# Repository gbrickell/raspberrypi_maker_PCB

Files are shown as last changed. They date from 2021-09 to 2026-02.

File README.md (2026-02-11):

# Raspberry Pi PCB v5.0

The aim of this project was to consolidate a number of components previously used in separate breadboard-based educational projects, along with some additional options, in a more robust, permanent assembly using a custom Printed Circuit Board (PCB). 
This new platform would then allow an even wider range of projects to be developed, but it should be noted that all the various uses profiled here can still be carried out without the use of the custom PCB which just makes the various connections to the Raspberry Pi a lot easier.

Full details about the project are published at <a href="https://onlinedevices.org.uk/Raspberry+Pi+Maker+PCB" target="_blank" >this link</a> and the designs for a small number of associated custom 3D printed components can be downloaded from <a href="https://www.prusaprinters.org/prints/68834-raspberry-pi-maker-PCB-stands" target="_blank">here</a>.

The various sections below provide more detail on:
 - the documentation made available in the 'documentation' folder;
 - the design details for the PCB made available in the 'PCB_design_files' folder; and
 - the software available as downloads from the 'Raspberry_Pi_SBC_code' folder.

## Documentation

A robust permanent module, that connects to the Raspberry Pi GPIO pins, can be created by soldering a set of components into the custom Printed Circuit Board (PCB v5.0). The module design, as shown below, includes a number of on-board devices that can be controlled by the Pi (e.g. buzzer, LEDs, etc.), but also allows a wide range of further components to be connected to the PCB enabling more Pi controlled systems to be built and explored.

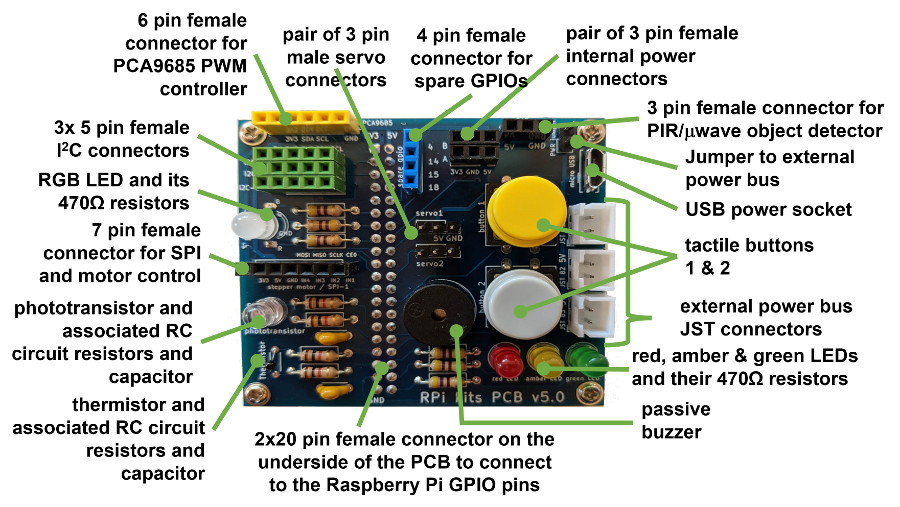
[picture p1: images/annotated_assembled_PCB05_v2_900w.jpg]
&nbsp; &nbsp; 

Documentation is made available for usage exploration of:
 - basic electronic functions
 - LCD, OLED and LED displays
 - servo, stepper and drive motor control
 - various sensors
 - 433Mz ASK/OOK RF communications, and 
 - image taking with a USB camera

## Custom PCB design

The custom PCB (now at v5.0) was designed using KiCAD and the layout has been defined to allow headers and other connectors for all the components needed to build a fully populated module.

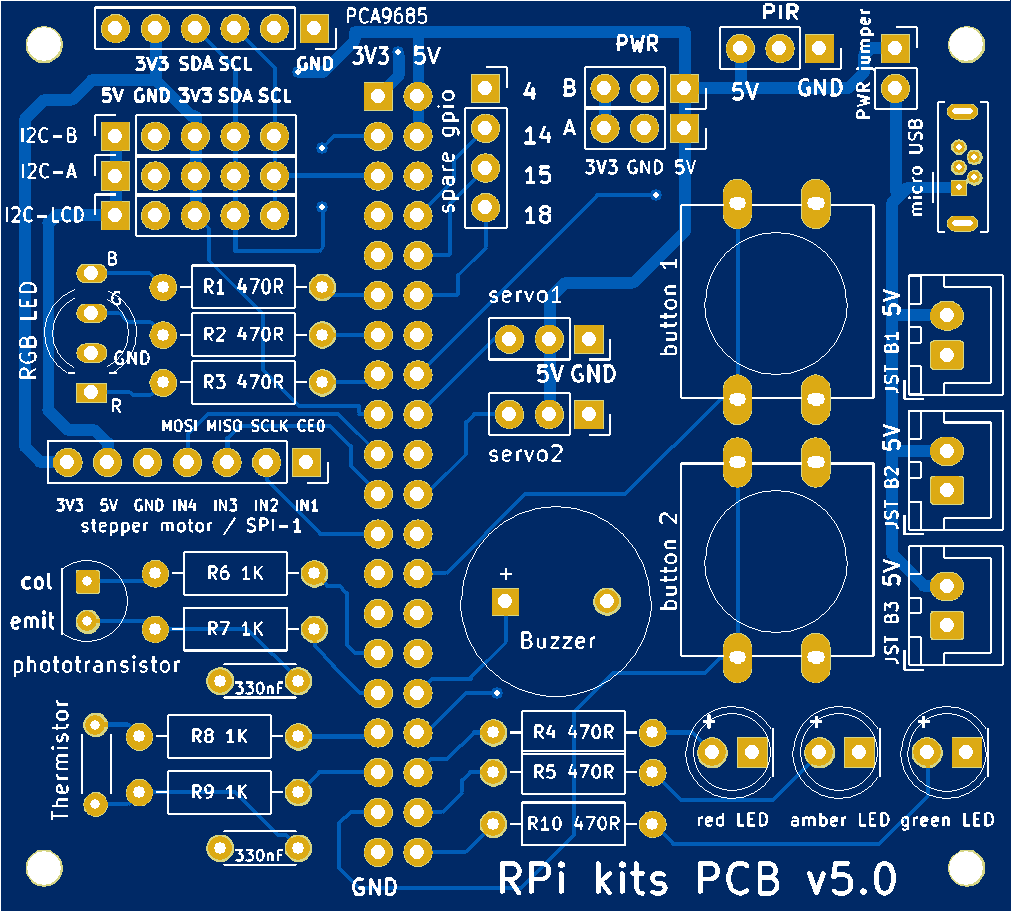
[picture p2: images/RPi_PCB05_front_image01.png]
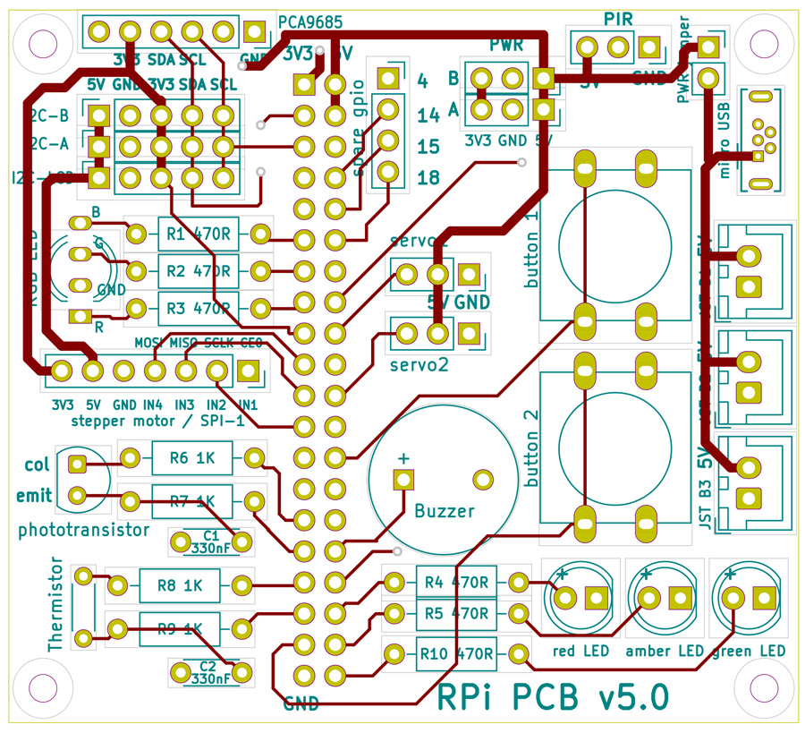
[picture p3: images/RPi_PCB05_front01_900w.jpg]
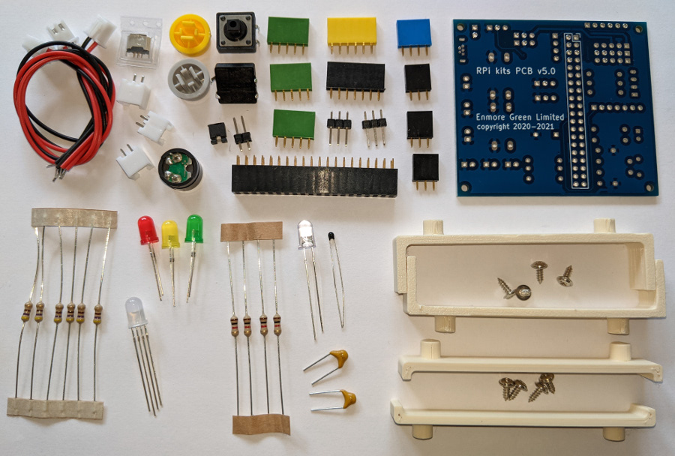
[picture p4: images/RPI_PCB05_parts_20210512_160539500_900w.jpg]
 &nbsp; &nbsp;  &nbsp; &nbsp;   

Gerber files for the PCB design can be downloaded from the PCB_design_files folder.

## Raspberry Pi SBC code
The code and documentation has been updated to allow for a generalised username instead of the 'old' default username 'pi', and for the use of Python using the Bookworm OS with the use of a Virtual Environment also described.

An installation script is also provided that not only downloads all the code and documentation but also installs all the various libraries/modules needed by the code.

Example code is provided, just for the 'basic electronics' exploration, using the Pi's Scratch offline versions 1.4, 2 and 3, so that all the common Raspberry Pi SBC formats that can run Scratch in some form has an option.

Python example code is provided for all the 'exploration' areas and can usually be run using the Thonny IDE on a Pi SBC, but suggested CLI commands for the user are also provided in the code as a comment, where the installed folders are assumed to be: /home/YOURUSERNAME/RPi_maker_PCB5/foldername/ where 'foldername' is for one of the specific areas that is being explored, e.g. displays, sensors, etc.

The image taking code also assumes various folders for the storage of different types of 'taken' images and these folders are not always auto-created so the code should be checked so that the appropriate folders can be created before the code is run.

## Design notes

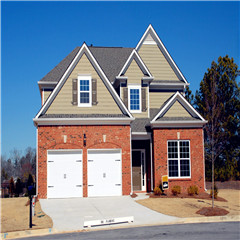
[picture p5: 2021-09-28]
Raspberry_Pi_SBC_code/displays/IPS_240X240_SPI/pic/pic-2.jpg

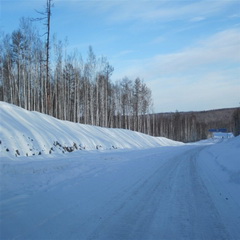
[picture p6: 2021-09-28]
Raspberry_Pi_SBC_code/displays/IPS_240X240_SPI/pic/pic-3.jpg

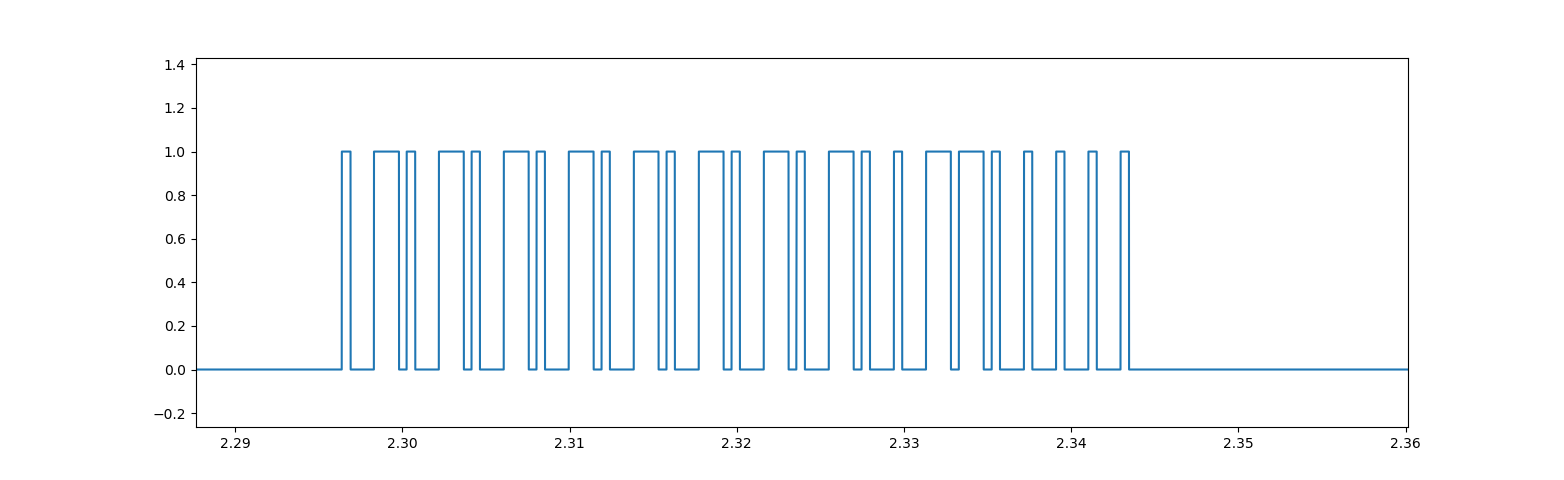
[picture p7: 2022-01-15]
images/button_B_signal.png

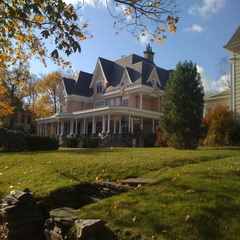
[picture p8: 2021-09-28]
Raspberry_Pi_SBC_code/displays/IPS_240X240_SPI/pic/pic-1.jpg

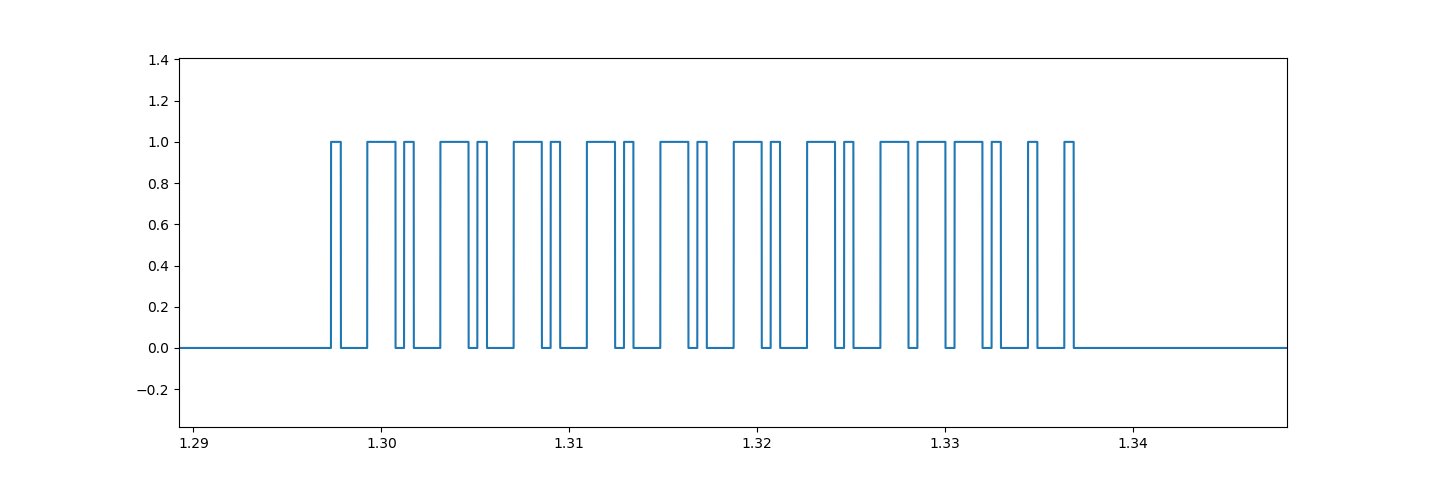
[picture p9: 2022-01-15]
images/button_A_signal.png

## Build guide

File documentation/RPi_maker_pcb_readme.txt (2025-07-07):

*********************************************************************************
RPi_maker_pcb_readme.txt - version control details for the Raspberry Pi Maker PCB
*********************************************************************************

required components version 2.0 September 2024
----------------------------------------------
  required components for use with the v5.0 PCB are listed in the RPi_PCB5_usage_documentation_v2-1.pdf
  and RPi_maker_pcb_getting_started_v2-0.pdf documents

  please note:
  ------------
  all electronic and electrical components need to be carefully recycled 
  but we would much prefer for you to pass this equipemnt on to another 
  user if you have no further use for it. 

*******************************************************************	
software & documentation version 2.0  September 2024
-------------------------------------------------------------------
  description: updated version with content to support usage with Raspberry Pi SBCs using the Bookworm OS 

  ** documentation ** 
    RPi_maker_pcb_readme.txt - this document which is updated whenever a new version is released
    RPi_maker_pcb_getting_started_v2-0.pdf - Raspberry Pi Maker PCB getting started leaflet v2.0 September 2024
    RPi_PCB5_usage_documentation_v2-1.pdf - Raspberry Pi Maker PCB detailed usage documentation v2.1 September 2024

  ** Scratch, Python and other software files **
  
  * Raspberry Pi single board computer (SBC) code:
  
  electronic basics
  -----------------
  Scratch 1.4 - LED_button_buzzer.sb
              - LED_button_flash.sb
			  - LED_flash.sb
			  - LED_red_green_flash.sb
			  - LED_RGB_flash.sb
  Scratch 2   - LED_button_buzzer.sb2
              - LED_button_flash.sb2
			  - LED_flash.sb2
			  - LED_red_green_flash.sb2 
			  - LED_RGB_flash.sb2
  Scratch 3   - LED_button_buzzer.sb3
              - LED_button_flash.sb3
			  - LED_flash.sb3
			  - LED_red_green_flash.sb3 
			  - LED_RGB_flash.sb3
  Python - LED_flash.py
	     - LED_red_green_flash.py
		 - LED_red_amber_green_flash.py
	     - LED_button_flash.py
	     - LED_button_buzzer.py
		 - buzzer_player.py
  web code      - LED1_flash_web.py
  web css       - normalize_advanced.css	
                - skeleton_advanced.css
  web images    - favicon.png
                - RPi_PCB05_20210419_160549156_900w.jpg
			    - RPi_PCB05_front_image01.png
  web templates - electronics_header_insert.html
                - electronics_layout.html
				- electronics_select_mode1.html
				- led1_setup_mode.html
				- run_led1.html

  image taking
  ------------
  Python - button_led_take_image.py
         - button_led_take_video.py
		 - button_take_image.py
	     - button_take_video.py
		 - button_timer_take_image.py
		 - button_timer_take_video.py
		 - PIR_take_image.py
		 - sort_number_symlink_files.py
		 - timelapse_cron_take_annotated_image.py
		 - timelapse_cron_take_image.py
  web code      - image_camera_usb_opencv_annotate.py
                - image_streaming_app_root_annotate.py
				- image_streaming_app_user_annotate.py
  web css       - normalize_advanced.css	
                - skeleton_advanced.css
  web images    - favicon.png
                - Starter_PCB01_20210518_132528401_900w.jpg
			    - Starter_PCB01_front_image.png
  web templates - cam_options_setup.html
                - cam_setup_mode.html
				- header_insert.html
				- layout.html
				- select_mode.html
				- stream_video_mode.html
  
  displays
  --------
  Python - code for IPS_240X240_SPI display
         - code for IPS_80x160_SPI display
		 - code for LCD_1602_i2c display
		 - code for MAX7219_7segment_LED display
		 - code for OLED_128x64_I2C display
		 - code for TM1637_7segment_LED display
    
  motor control
  -------------
  Python - code for drive motor control
         - code for servo motor control
		 - code for stepper motor control
  web code - web front end code for motor control
  
  RF_communication
  ----------------
  Python - code for C218D001C + FS1000A communications
         - code for RXB8 communications
		 - code for SRX882 + STX882 communications
  
  sensors
  -------
  Python - code for light sensor data capture
         - code for magnetic sensor data capture
		 - code for MPR121 touch sensor data capture
		 - code for object_detection sensor data capture
		 - code for pressure sensor data capture
		 - code for temperature sensor data capture
		 - code for TTP229 touch keypad data capture

copyright 2021-2024 Geoff Brickell

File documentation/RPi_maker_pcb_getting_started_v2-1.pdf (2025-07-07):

The aim of this evolving project is to provide access to an expanding library of example code to allow a digital maker to explore and control many different components and devices.
This is achieved by using a custom PCB with a set of defined components, listed above, to assemble a populated module that can connect to any of the family of Raspberry Pi single board computers (SBCs) with 2x20 GPIO pins. Example software is available to download to Raspberry Pi SBCs along with a “Raspberry Pi Maker PCB Usage Documentation” PDF providing assembly and detailed usage instructions, along with other support documents.
Whilst any model of 2x20 GPIO pin Raspberry Pi is OK, if a new Pi is being purchased the Raspberry Pi5 or Pi400 with at least 2GB of memory is recommended as well as a SD card that is at least 32GB. You should also be using the latest Bookworm version of the operating system. If you have an earlier operating system version, you should carry out an update or create/ install a new SD card before installing the Raspberry Pi software and documentation detailed overleaf, for the use of this Maker PCB.
© 2021-25 Geoff Brickell | version 2.1 | July 2025

## Required component summary:

1x printed circuit board (PCB) | 4x 1kΩ resistors
1x red LED | 2x 330nF capacitors
1x amber LED | 1x Thermistor 10kΩ NTC
1x green LED | 1x Phototransistor
1x RGB LED | 2x tactile buttons
6x 470Ω resistors | 1x passive buzzer
3x JST sockets + plugs with leads | 1x USB type B micro socket
1x 1row x 6P female yellow header | 3x 1row x 5P female green headers
1x 1row x 4P female blue header | 3x 1row x 3P female black headers
1x 1row x 7P female black header | 1x 2row x 20P female black header
2x 1row x 3P male black header | 1x + 1x 1row x 2P male black header + jumper
2x 3D printed PCB ‘stands’ + 4x 6mm M2 self-tap screws | 2x 3D printed Raspberry Pi ‘stands’ + 4x 6mm M2 self-tap screws

# Getting started with your Raspberry Pi Maker PCB

$ wget -O /home/YOURUSERNAME/RPi_maker_PCB5.sh https://onlinedevices.org.uk/dl1389 (take great care to type this correctly and if you get an error then recheck it)
-O above is an upper case letter O and the last set of characters are lower case DL1389
© 2021-25 Geoff Brickell | version 2.1 | July 2025

Only 5V DC power supplies, 5V rechargeable battery banks, or 4xAA battery packs should be connected to the PCB’s separate ‘power bus’. In addition the ’power bus’ should only be interconnected to the PCB’s main 5V power line, using the ‘jumper’ connection point, if the supply to the ‘power bus’ is at a safe level for the Raspberry Pi.
Only approved 5V DC power supplies should be used to power a Raspberry Pi, please refer to any Regulatory Compliance and Safety Information provided with your Raspberry Pi.
For each of the projects/methods described in the main documentation for the Raspberry Pi you should ensure that the Pi is not powered when connecting the PCB to the Raspberry Pi.
Assembling a complete PCB is a significant soldering task for which some experience at soldering is needed, but with some adult supervision, this Maker project is aimed at ages 10 and above. However, with an adult carrying out the soldering of components onto the PCB, ages as young as 7 should be able to run the projects, although at this early age not all the physics and maths associated with the projects may be fully understood.

You then run the following two commands to prepare and run the downloaded control script, which when run will then download all the files and store them on your Raspberry Pi in a main folder and various subfolders starting at /home/YOURUSERNAME/RPi_maker_kit5, as well as installing the various libraries/modules needed by the software examples.
$ chmod +x RPi_maker_PCB5.sh
$ ./RPi_maker_PCB5.sh
The downloaded documentation files provide you with very detailed information on the various ways that the populated PCB can be used.

To get started with a Raspberry Pi, you need to set up and configure your Pi with a screen, keyboard plus mouse and connect it to the internet, but this is not covered here as other publicly available resources can help you do this. With your Raspberry Pi started in ‘Desktop’ mode and connected to the Internet, a usage document (PDF) for the Kit as well as other support documents and all the software for each project and method can be downloaded to your Raspberry Pi by running the following commands in an opened ‘Terminal’ window.
N.B. the $ sign in the command lines below signifies the prompt character in your terminal application, which you do not need to type.
First run the following command to download an initial control script where you substitute your username for YOURUSERNAME:

## Software & documentation download:

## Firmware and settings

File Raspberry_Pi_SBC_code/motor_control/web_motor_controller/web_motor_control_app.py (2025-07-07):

#!/usr/bin/python

# RPi PCB version of servo_stepper_control_app.py
# Servo & Stepper Motor PCB Flask controller: python code as part of a Flask based web server system
# 
# this version of the Flask app needs to be run using sudo as it uses the 
#  'production' Flask server - see the code at the very end of the listing
# command to run: 
#            sudo python3 ./RPi_maker_PCB5/motor_control/web_motor_controller/web_motor_control_app.py
# 
# provides browser access for the servo control of two semaphore 'flags' using a PCA9685 I2C controller
#  and a stepper motor that drives the needle of a gauge indicating the CPU temeperature
# the two servos are connected to channels 0 (left servo) and 15 (right servo) and are moved to a set of positions 
#  depending upon a text message that is input using a HTML template

#+-+-+-+-+-+-+-+-+-+-+-+-+-+-+-+-+-+-+-+-+-+-+-+-+-+-+-+-+-+-+-+-+-+-+-+-+-+-+-+-+-+-+-+
#
# function to return the CPU temperature for the stepper gauge
#
#+-+-+-+-+-+-+-+-+-+-+-+-+-+-+-+-+-+-+-+-+-+-+-+-+-+-+-+-+-+-+-+-+-+-+-+-+-+-+-+-+-+-+-+
# Return CPU temperature as a character string                                     
def getCPUtemperature():
    res = os.popen('vcgencmd measure_temp').readline()
    return(res.replace("temp=","").replace("'C\n",""))

#+-+-+-+-+-+-+-+-+-+-+-+-+-+-+-+-+-+-+-+-+-+-+-+-+-+-+-+-+-+-+-+-+-+-+-+-+-+-+-+-+-+-+-+
#
# function to set the GPIO pins in an individual Seq row - used for the stepper gauge
#
#+-+-+-+-+-+-+-+-+-+-+-+-+-+-+-+-+-+-+-+-+-+-+-+-+-+-+-+-+-+-+-+-+-+-+-+-+-+-+-+-+-+-+-+
def setGPIOrow(row):
    for pin in range(0, 4):   # loop through the GPIO pins setting them to HIGH or LOW according to the Seq{} value
      xpin = StepPins[pin]
      if Seq[row][pin]!=0:      # if not 0 then assume 1 so set HIGH (True)
        #print (" Enable GPIO %i" %(xpin))
        GPIO.output(xpin, True)
      else:
        GPIO.output(xpin, False)        # if = 0 then set LOW (False)
    # Wait before returning - a wait time is needed as the control board may not be able to keep up
    time.sleep(WaitTime)

    return()

#+-+-+-+-+-+-+-+-+-+-+-+-+-+-+-+-+-+-+-+-+-+-+-+-+-+-+-+-+-+-+-+-+-+-+-+-+-+-+-+-+-+-+-+
#
# function to move n sequences in either direction where 1 sequence is 4 steps
#
#+-+-+-+-+-+-+-+-+-+-+-+-+-+-+-+-+-+-+-+-+-+-+-+-+-+-+-+-+-+-+-+-+-+-+-+-+-+-+-+-+-+-+-+
def stepmotor(direction, sequences, position):
    # 'direction' is either -1 for backwards or +1 for forwards
    # 'sequences' is the number of four-step sequences to move
    # 'position' is the current stepper motor position measured in steps between 0 and 2000

    #print ("direction, sequences, position: " + str(direction) + " - " + str(sequences) + " - " + str(position) )

    # check we are not going off scale
    if direction == 1 and (position + 4*sequences) > 2000 :
        sequences = (2000 - position)/4    # decrease the number of sequences to just reach end of scale
        offscale = "plus"                  # set the offscale parameter to indicate 'off to the plus'
        position = 2000                    # set the new current position after the movement below
        #print ("off scale plus")

    elif direction == -1 and (position - 4*sequences) < 0 :
        sequences = position/4            # decrease the number of sequences to just reach end of scale
        offscale = "minus"                # set the offscale parameter to indicate 'off to the minus'
        position = 0                      # set the new current position after the movement below
        #print ("off scale minus")

    else:
        offscale = "ok"                   # set the offscale parameter to indicate all ok
        position = position + 4*direction*sequences
        #print ("scale ok")

    tstart = time.time()   # start the clock by recording the current time - not actually using this at the moment
    for seqloop in range (0, sequences):
        #print ("sequence loop count: " +str(seqloop))

        # do one sequence of four steps
        # set the GPIO pins HIGH/LOW according to the pin sequence in Seq and 
        #  either go through the array forwards or backwards
        if direction == -1:
            for row in range(3, -1, -1):     # this does rows 3, 2, 1, 0
                #print ("pin row: " + str(row))
                setGPIOrow(row)
        elif direction == 1:
            for row in range(0, 4, 1):       # this does rows 0, 1, 2, 3
                #print ("pin row: " + str(row))
                setGPIOrow(row)

    #print ("number of sequences completed: " + str(seqloop+1))

    return (position, offscale)




#########################################################
## function to send a semaphore message with the servos
#########################################################

def send_semaphore(message_string):

    message_string = message_string.upper()   # convert message to uppercase
    print ("text message in UPPER case is: " + message_string)
    message_array = list(message_string)      # put the characters of the string into an array
    #print ("message as an array is: " + str(message_array))

    # loop through the individual letters in the 'message' string
    for i in range (0, len(message_string)):
        #print i
        #print message_array[i]
        print ("Working on the letter: " + str(i) + " - " + str(message_array[i]))
        # find the chr in the reference letters array to get the two servo angles for that letter
        for irow, row in enumerate(letters):  # loop through the rows and columns of the reference letters array
            #print ("looking at letters row: " + str(irow))
            #print ("looking at letters column 0: " + str(letters[irow][0]) )
            if letters[irow][0] == message_array[i]:   # we have found the row - the column should always be 0
                #print ("letters row is: " + str(irow))
                print ("left and right servo angles are: " + str(letters[irow][1]) + " and " + str(letters[irow][2]))
                # set the servo positions with the 'found' servo angles
                set_servo('left', letters[irow][1])
                set_servo('right', letters[irow][2])
                time.sleep (3)    # wait a short interval between each letter being 'flagged'
                break
            if irow > 19:    # if we reach the end of the rows in the reference array then the letter is not found
                print ("message letter " + str(i) + " not found")

    print ("message ends")
    # set servos to zero position
    set_servo('left', 0)
    set_servo('right', 0)

    return ()

#################################################################
## function to set the servo position for the semaphore demo
#################################################################
def set_servo(side, angle):
    # 'side' is either left or right to indicate which servo to set
    # 'angle' is the angle 'found' from the reference letters array for the letter to be sent
    # the angle is either 0, 45, 90, 135, or 180 which is then translated into a PWM pulse value
    if side == "left":
        channel = 0
        if angle == 0:
            servo_pulse = left0
        elif angle == 45:
            servo_pulse = left45
        elif angle == 90:
            servo_pulse = left90
        elif angle == 135:
            servo_pulse = left135
        elif angle == 180:
            servo_pulse = left180
        else:
            print ("incorrect servo angle set for left side")
            return ()

    elif side == "right":
        channel = 15
        if angle == 0:
            servo_pulse = right0
        elif angle == 45:
            servo_pulse = right45
        elif angle == 90:
            servo_pulse = right90
        elif angle == 135:
            servo_pulse = right135
        elif angle == 180:
            servo_pulse = right180
        else:
            print ("incorrect servo angle set for right side")
            return ()

    else:
        print ("incorrect side value in the set_servo function")
        return ()

    # the line below uses the I2C servo control board (PCA9685) library to move the servo
    pwm.set_pwm(channel, 0, servo_pulse)
    return ()


#+-+-+-+-+-+-+-+-+-+-+-+-+-+-+-+-+-+-+-+-+-+-+-+-+-+-+-+-+-+-+-+-+-+-+-+-+-+-+-+-+-+-+-+
#
# main code 
#
#+-+-+-+-+-+-+-+-+-+-+-+-+-+-+-+-+-+-+-+-+-+-+-+-+-+-+-+-+-+-+-+-+-+-+-+-+-+-+-+-+-+-+-+

#import sys
import os                 # this imports the module to allow various system functions too be used
import time               # this imports the module to allow various time functions to be used
import RPi.GPIO as GPIO   # this imports the module to allow the GPIO pins to be easily utilised

import Adafruit_PCA9685   # this imports a library that interfaces with the I2C servo control board (PCA9685)
                          #   and provides a set of PWM (pulse width modulation) functions the board can supply

# import the various Flask libraries that are needed
from flask import Flask, render_template
from flask import request

# Use BCM GPIO references
# instead of physical pin numbers
GPIO.setmode(GPIO.BCM)

# Define GPIO signals to use                                                                                                                         
# BCM numbering: GPIO19,GPIO20,GPIO21,GPIO16 connected to IN1, IN2, IN3 and IN4 on the ULN2003 control board
StepPins = [19,20,21,16]    # set all the GPIO pins into an array

# Set all the stepper control GPIO pins as output and as LOW
for pin in StepPins:
  #print ("Setup pins")
  GPIO.setup(pin,GPIO.OUT)
  GPIO.output(pin, False)

# Define the phase sequence for the unipolar stepper motor i.e.
# for GPIO pins 6, 13, 16, & 20 connected to the drive coils using  
# the blue & yellow (coil 1) plus pink & orange (coil 2) wires
# the red wire is the common centre tap for both drive coils

# Full step sequence: sets two phases at a time producing a 0.18 degree step angle 
#  and twice the torque as two coils are energised at the same time
#  the Seq array is for 4 steps at a time

Seq = [[1,1,0,0],
       [0,1,1,0],
       [0,0,1,1],
       [1,0,0,1]]

WaitTime = 3.0/float(1000)     # default wait time that seems to work OK
# other stepper gauge initial parameter values
currentposition = 0
errorscale = "ok"
lasttemp = 45.0

# Initialise the servo control board assuming it has its 
#  default address of hex 40 (0x40) and is the only device on the bus
#  this can be checked by running "sudo i2cdetect -y 1"
#  for all recent RPi models the port# is 1 in the above 'detect' command - but for pre-Oct'12 models it is 0
pwm = Adafruit_PCA9685.PCA9685()

# If for some reason the I2C device set up is not the default then use the following:
#    pwm = Adafruit_PCA9685.PCA9685(address=0x??, busnum=?)

pwm.set_pwm_freq(50)   # set the PWM frequency to 50Hz - as recommended for servos

# set the 5 servo pulse lengths for the 0, 45, 90, 135 and 180 degree positions for both left and right servos
# each number may have to be fine tuned for the specific servo - see the support documentation for more details

left0 = 580 
left45 = 465
left90 = 350
left135 = 240
left180 = 130

right0 = 160 
right45 = 262
right90 = 365
right135 = 490
right180 = 615

# reference signal arrays i.e. letters and special signals

# NB some letters (H, I, O, W, X & Z) cannot be sent as they need rotations that are not (yet?) possible
letters = [['A',45,0],
           ['B',90,0],
           ['C',135,0],
           ['D',180,0],
           ['E',0,135],
           ['F',0,90],
           ['G',0,45],
           ['J',180,90],
           ['K',45,180],
           ['L',45,135],
           ['M',45,90],
           ['N',45,45],
           ['P',90,180],
           ['Q',90,135],
           ['R',90,90],
           ['S',90,45],
           ['T',135,180],
           ['U',135,135],
           ['V',180,45],
           ['Y',135,90],
           [' ',0,0]]

# the specials array is not currently used but is included for possible future use
specials = [['space',0,0],         # also included above
            ['error_up',135,135],
            ['error_down',45,45],
            ['cancel',135,45]]

semaphore_message = "default"

servo_stepper_app01 = Flask(__name__)  # creates a Flask object called servo_stepper_app01

##################################################################################################
# this route goes to the main select mode routine when the URL root is selected
# to select either the servo semaphore activity, the stepper motor 'gauge' activity, or to reboot
##################################################################################################
@servo_stepper_app01.route("/") # run the code below this function when the URL root is accessed
def start():
    select_mode = "selection routine",
    template_data = {
        'title' : "home page",
    }

    return render_template('select_motor_mode.html', **template_data)


#########################################################################################################
# this route defines the actions selected when the servo & stepper motor system is in the selection mode
#########################################################################################################
@servo_stepper_app01.route("/<choice_mode>")  # run the code below this function when URL /<choice_mode> is accessed from select_motor_mode.html where choice_mode is a variable
def motor_selection(choice_mode=None):
    none_selected = "no motor selected"

    # update time now       
    timenow = time.strftime('%H:%M %Z')
    print ("time updated in choice_mode route")    

    if choice_mode == 'servo_semaphore':   # run this section of code if 'servo_semaphore' is selected at the template

        # template data: individual parameters that are passed for use in the template to render the browser display
        template_data = {
            'title' : "servo semaphore system selected", # this sets the browser title template parameter
            'time_now' : timenow,                        # this sets the current time template parameter
            'sem_message' : semaphore_message,           # this sets the current semaphore message
        }

        # echo the current values of the servo system to the screen
        print ("semaphore message: " + semaphore_message)

        return render_template('semaphore_message.html', **template_data)   # run the 'semaphore_message.html' template


    elif choice_mode == 'stepper_gauge':   # run this section of code if 'stepper_gauge' is selected at the template

        # template data: individual parameters that are passed for use in the template to render the browser display
        template_data = {
            'title' : "stepper gauge system selected", # this sets the browser title template parameter
            'time_now' : timenow,                      # this sets the current time template parameter
        }

        # echo the values of the stepper gauge system to the screen
        # nothing for now

        return render_template('stepper_gauge_setup.html', **template_data) # run the 'stepper_gauge_setup.html' template


    elif choice_mode == 'reboot':
        os.system("sudo reboot")    # this does an immediate reboot of the system


    else:  # shouldn't ever arrive here but run this section of code if  neither 'servo_semaphore' nor 'stepper_gauge' nor 'reboot' are selected at the template
        template_data = {
            'title' : "no choice made",
        }
        return render_template('select_motor_mode.html', **template_data)




##################################################################################################################
# this route defines the actions selected when the servo semaphore activity is 'on' and in 'message input' mode
##################################################################################################################
@servo_stepper_app01.route("/servo_semaphore/<semaphore_command>")  # run the code below this function when URL /servo_semaphore/<semaphore_command> is accessed where <semaphore_command> is a variable
def semaphore_active(semaphore_command=None):
    no_command = "no command given"

    # update time now
    timenow = time.strftime('%H:%M %Z')
    print ("time updated in servo_semaphore route")

    if semaphore_command == 'send_updated_message':
        # execute this set of code to send a revised semaphore message

        print ("send updated message path selected")
        print ("request method: " + str(request.method))
        print ("new message text: " + str(request.args.get('message')))
        semaphore_message = str(request.args.get('message'))

        # now 'signal' the revised semaphore message
        print ("start of new semaphore message")

        send_semaphore(semaphore_message)

        print ("end of new semaphore message")
        # end of semaphore sending - return to the message input screen

        # template data: individual parameters that are passed for use in the template to render the browser display
        template_data = {
            'title' : "send new message selected", # this sets the browser title template parameter
            'time_now' : timenow,                  # this sets the current time template parameter
            'sem_message' : semaphore_message,     # this sets the revised semaphore message

        }

        return render_template('semaphore_message.html', **template_data)    # run the 'semaphore_message.html' template

    elif semaphore_command == 'send_same_message':
        # execute this set of code to do a repeat send of the unchanged semaphore message

        print ("send existing message path selected")
        print ("request method: " + str(request.method))
        print ("message text: " + str(request.args.get('message')))
        semaphore_message = str(request.args.get('message'))

        print ("existing message text: " + semaphore_message)

        # now 'signal' the same repeated semaphore message
        print ("start of repeat send of semaphore message")

        send_semaphore(semaphore_message)

        print ("end of repeat send of semaphore message")
        # end of semaphore sending - return to the message input screen

        # template data: individual parameters that are passed for use in the template to render the browser display
        template_data = {
            'title' : "send new message selected", # this sets the browser title template parameter
            'time_now' : timenow,                  # this sets the current time template parameter
            'sem_message' : semaphore_message,     # this sets the revised semaphore message

        }

        return render_template('semaphore_message.html', **template_data)    # run the 'semaphore_message.html' template


    elif semaphore_command == 'select':

        print ("select motor option path selected")
        template_data = {
            'title' : "none selected",
        }
        print (" going back to select .....")

        return render_template('select_motor_mode.html', **template_data)

    else:    # should not ever get here but added just in case

        print ("unknown selection path?")
        template_data = {
            'title' : "none selected",
        }
        print (" going back to select .....")

        return render_template('select_motor_mode.html', **template_data)
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

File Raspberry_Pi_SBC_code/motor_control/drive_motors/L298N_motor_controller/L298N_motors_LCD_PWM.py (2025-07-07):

#!/usr/bin/python

# RPi PCB version of L298N_2motors_test01.py
# using a L298N to control the motors with PWM

# command to run:  python3 ./RPi_maker_PCB5/motor_control/drive_motors/L298N_motor_controller/L298N_motors_LCD_PWM.py


#+-+-+-+-+-+-+-+-+-+-+-+-+-+-+-+-+-+-+-+-+-+-+-+-+-+-+-+-+-+-+-+-+-+-+-+-+-+-+-+-+-+-+-+
#
# Raspberry Pi L298N more developed PWM motor functions but based upon the article at 
#  http://www.instructables.com/id/Control-DC-and-stepper-motors-with-L298N-Dual-Moto/
#  which describes the L298N motor controller use with an Arduino Uno
# 
#  N.B. depending upon how the motors are connected the motor direction
#    signals to the in1, in2, in3 nd in4 pins may need to be reversed
#
#+-+-+-+-+-+-+-+-+-+-+-+-+-+-+-+-+-+-+-+-+-+-+-+-+-+-+-+-+-+-+-+-+-+-+-+-+-+-+-+-+-+-+-+

def forward_pwm(dutycycleA, dutycycleB):   # A is right and B is left
    # separate duty cycles are set so that each motor can be fine tuned if they vary in performance
    # in1, in2, in3 and in4 to be adjusted so that both motors go fwd

    print ("forward " + str(dutycycleA) + " - " +str(dutycycleB))

    # set enA (right motor) with the PWM dutycycle
    pwm_enA.start(dutycycleA)
    # set in1 off and in2 on i.e. LOW - HIGH for forward motion
    GPIO.output(in1, 0)
    GPIO.output(in2, 1)

    # set enB (left motor) with the PWM dutycycle
    pwm_enB.start(dutycycleB)
    # set in3 off and in4 on -i.e. LOW - HIGH for forward motion
    GPIO.output(in3, 0)
    GPIO.output(in4, 1)
 
def backward_pwm(dutycycleA, dutycycleB):  # A is right and B is left
    # in1, in2, in3 and in4 to be adjusted so that both motors go back

    print ("backward " + str(dutycycleA) + " - " +str(dutycycleB))

    # set enA (right motor) with the PWM dutycycle
    pwm_enA.start(dutycycleA)
    # set in1 on and in2 off i.e. HIGH - LOW for backward motion
    GPIO.output(in1, 1)
    GPIO.output(in2, 0)

    # set enB (left motor) with the PWM dutycycle
    pwm_enB.start(dutycycleB)
    # set in3 on and in4 off i.e. HIGH - LOW for backward motion
    GPIO.output(in3, 1)
    GPIO.output(in4, 0)
 
def stop_pwm(mode):
    if mode == "brake":
        print ("brake stop")
        # motor braking
        # set enA with 100% PWM dutycycle
        pwm_enA.start(100)
        # set in1 off and in2 off i.e. LOW- LOW for no motion
        GPIO.output(in1, 0)
        GPIO.output(in2, 0)
        # set enB with 100% PWM dutycycle
        pwm_enB.start(100)
        # set in3 off and in4 off i.e. LOW- LOW for no motion
        GPIO.output(in3, 0)
        GPIO.output(in4, 0)

    elif mode == "coast":
        print ("coast stop")
        # coasting
        # set enA with 0% PWM dutycycle
        pwm_enA.start(0)
        # set in1 off and in2 off i.e. LOW- LOW for no motion
        GPIO.output(in1, 0)
        GPIO.output(in2, 0)
        # set enB with 0% PWM dutycycle
        pwm_enB.start(0)
        # set in3 off and in4 off i.e. LOW- LOW for no motion
        GPIO.output(in3, 0)
        GPIO.output(in4, 0)
 
def turnRight_pwm(turn_time, dutycycleB):   # left motor fwd & right motor off
    print ("turn Right " + str(turn_time) + " - " +str(dutycycleB))

    # set enA (right motor) with 0% PWM dutycycle
    pwm_enB.start(0)
    # set in1 off and in2 off i.e. LOW - LOW for no motion 
    GPIO.output(in1, 0)
    GPIO.output(in2, 0)

    # set enB (left motor) with the passed PWM dutycycle
    pwm_enB.start(dutycycleB)
    # set in3 off and in4 on -i.e. LOW - HIGH for forward motion
    GPIO.output(in3, 0)
    GPIO.output(in4, 1)

    time.sleep(turn_time) # only run the motors for the set amount of turn_time seconds
    stop_pwm("brake")     # stop the motors after the turn
 
def turnLeft_pwm(turn_time, dutycycleA):   # right motor (A) fwd & left motor (B) off
    print ("turn Left " + str(turn_time) + " - " +str(dutycycleA))

    # set enB (left motor) with 0% PWM dutycycle
    pwm_enB.start(0)
    # set in3 off and in4 off i.e. LOW - LOW for no motion
    GPIO.output(in3, 0)
    GPIO.output(in4, 0)

    # set enA (right motor) with the passed PWM dutycycle
    pwm_enA.start(dutycycleA)
    # set in1 off and in2 on i.e. LOW - HIGH for forward motion
    GPIO.output(in1, 0)
    GPIO.output(in2, 1)
 
    time.sleep(turn_time) # only run the motors for the set amount of turn_time seconds
    stop_pwm("brake")     # stop the motors after the turn
 
def spinRight_pwm(spin_time, dutycycleA, dutycycleB):   # left motor (B) fwd & right motor (A) back
    print ("spin Right " + str(spin_time) + " - " +str(dutycycleA) + " - " +str(dutycycleB))

    # set enA (right motor) with the passed PWM dutycycle
    pwm_enA.start(dutycycleA)
    # set in1 on and in2 off i.e. HIGH - LOW for backward motion
    GPIO.output(in1, 1)
    GPIO.output(in2, 0)

    # set enB (left motor) with the passed PWM dutycycle
    pwm_enB.start(dutycycleB)
    # set in3 off and in4 on -i.e. LOW - HIGH for forward motion
    GPIO.output(in3, 0)
    GPIO.output(in4, 1)

    time.sleep(spin_time) # only run the motors for the set amount of spin_time seconds
    stop_pwm("brake")     # stop the motors after the spin
   
def spinLeft_pwm(spin_time, dutycycleA, dutycycleB):   # left motor back & right motor fwd
    print ("spin Left " + str(spin_time) + " - " +str(dutycycleA) + " - " +str(dutycycleB))

    # set enA (right motor) with the passed PWM dutycycle
    pwm_enA.start(dutycycleA)
    # set in1 off and in2 on i.e. LOW - HIGH for forward motion
    GPIO.output(in1, 0)
    GPIO.output(in2, 1)

    # set enB (left motor) with the passed PWM dutycycle
    pwm_enB.start(dutycycleB)
    # set in3 on and in4 off i.e. HIGH - LOW for backward motion
    GPIO.output(in3, 1)
    GPIO.output(in4, 0)

    time.sleep(spin_time) # only run the motors for the set amount of spin_time seconds
    stop_pwm("brake")     # stop the motors after the spin


#+-+-+-+-+-+-+-+-+-+-+-+-+-+-+-+-+-+-+-+-+-+-+-+-+-+-+-+-+-+-+-+-+-+-+-+-+-+-+-+-+-+-+-+
#
# main code
#
#+-+-+-+-+-+-+-+-+-+-+-+-+-+-+-+-+-+-+-+-+-+-+-+-+-+-+-+-+-+-+-+-+-+-+-+-+-+-+-+-+-+-+-+

# import the LCD driver code, initalise the LCD and clear the screen
import I2C_LCD_driver
mylcd = I2C_LCD_driver.lcd()
mylcd.lcd_clear()  # clear LCD screen

import RPi.GPIO as GPIO # Import the GPIO Library
import time # Import the Time library

# Set the GPIO modes
GPIO.setmode(GPIO.BCM)
GPIO.setwarnings(False)

# L298N setup code
# Define Outputs from RPi to L298N - variable names are as per the L298N pin labels
# the IN1-IN4 pins 'borrow' the PCB stepper motor / SPI connections on the 7P female connector
# enA and enB use two of the spare GPIO pins
enA = 15   # this will be a software set PWM pin
in1 = 8
in2 = 11
enB = 18   # this will be a software set PWM pin
in3 = 9
in4 = 10

# Set the GPIO Pin mode
GPIO.setup(enA, GPIO.OUT)
GPIO.setup(in1, GPIO.OUT)
GPIO.setup(in2, GPIO.OUT)
GPIO.setup(enB, GPIO.OUT)
GPIO.setup(in3, GPIO.OUT)
GPIO.setup(in4, GPIO.OUT)
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

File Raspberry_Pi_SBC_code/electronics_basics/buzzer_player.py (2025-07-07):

#!/usr/bin/env python
#---------------------------------------------------
# This is free and unencumbered software released into the public domain.

# updated for use with maker PCB 5 Apr'21
# command: python3 /home/pi/RPi_maker_PCB5/electronic_basics/buzzer_player.py
#
# Anyone is free to copy, modify, publish, use, compile, sell, or
# distribute this software, either in source code form or as a compiled
# binary, for any purpose, commercial or non-commercial, and by any
# means.
#
# In jurisdictions that recognize copyright laws, the author or authors
# of this software dedicate any and all copyright interest in the
# software to the public domain. We make this dedication for the benefit
# of the public at large and to the detriment of our heirs and
# successors. We intend this dedication to be an overt act of
# relinquishment in perpetuity of all present and future rights to this
# software under copyright law.
#
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
# For more information, please refer to <http://unlicense.org>
#---------------------------------------------------
# 
#		Passive buzzer 			   Pi 
#			VCC ----------------- 3.3V
#			GND ------------------ GND
#			SIG ---------------- Pin Gpio12
#
#		some notes for melodies were taken from:
#		http://www.astlessons.com/pianoforkids1.html
#		http://www.astlessons.com/pianoforkids2.html
#		where you can get more notes
#
#---------------------------------------------------
import RPi.GPIO as GPIO
import time

buzzer_pin = 12

notes = {
    'B0' : 31,
    'C1' : 33, 'CS1' : 35,
    'D1' : 37, 'DS1' : 39,
    'EB1' : 39,
    'E1' : 41,
    'F1' : 44, 'FS1' : 46,
    'G1' : 49, 'GS1' : 52,
    'A1' : 55, 'AS1' : 58,
    'BB1' : 58,
    'B1' : 62,
    'C2' : 65, 'CS2' : 69,
    'D2' : 73, 'DS2' : 78,
    'EB2' : 78,
    'E2' : 82,
    'F2' : 87, 'FS2' : 93,
    'G2' : 98, 'GS2' : 104,
    'A2' : 110, 'AS2' : 117,
    'BB2' : 123,
    'B2' : 123,
    'C3' : 131, 'CS3' : 139,
    'D3' : 147, 'DS3' : 156,
    'EB3' : 156,
    'E3' : 165,
    'F3' : 175, 'FS3' : 185,
    'G3' : 196, 'GS3' : 208,
    'A3' : 220, 'AS3' : 233,
    'BB3' : 233,
    'B3' : 247,
    'C4' : 262, 'CS4' : 277,
    'D4' : 294, 'DS4' : 311,
    'EB4' : 311,
    'E4' : 330,
    'F4' : 349, 'FS4' : 370,
    'G4' : 392, 'GS4' : 415,
    'A4' : 440, 'AS4' : 466,
    'BB4' : 466,
    'B4' : 494,
    'C5' : 523, 'CS5' : 554,
    'D5' : 587, 'DS5' : 622,
    'EB5' : 622,
    'E5' : 659,
    'F5' : 698, 'FS5' : 740,
    'G5' : 784, 'GS5' : 831,
    'A5' : 880, 'AS5' : 932,
    'BB5' : 932,
    'B5' : 988,
    'C6' : 1047, 'CS6' : 1109,
    'D6' : 1175, 'DS6' : 1245,
    'EB6' : 1245,
    'E6' : 1319,
    'F6' : 1397, 'FS6' : 1480,
    'G6' : 1568, 'GS6' : 1661,
    'A6' : 1760, 'AS6' : 1865,
    'BB6' : 1865,
    'B6' : 1976,
    'C7' : 2093, 'CS7' : 2217,
    'D7' : 2349, 'DS7' : 2489,
    'EB7' : 2489,
    'E7' : 2637,
    'F7' : 2794, 'FS7' : 2960,
    'G7' : 3136, 'GS7' : 3322,
    'A7' : 3520, 'AS7' : 3729,
    'BB7' : 3729,
    'B7' : 3951,
    'C8' : 4186, 'CS8' : 4435,
    'D8' : 4699, 'DS8' : 4978
}



melody = [
  notes['E7'], notes['E7'], 0, notes['E7'],
  0, notes['C7'], notes['E7'], 0,
  notes['G7'], 0, 0,  0,
  notes['G6'], 0, 0, 0,
 
  notes['C7'], 0, 0, notes['G6'],
  0, 0, notes['E6'], 0,
  0, notes['A6'], 0, notes['B6'],
  0, notes['AS6'], notes['A6'], 0,
 
  notes['G6'], notes['E7'], notes['G7'],
  notes['A7'], 0, notes['F7'], notes['G7'],
  0, notes['E7'], 0, notes['C7'],
  notes['D7'], notes['B6'], 0, 0,
 
  notes['C7'], 0, 0, notes['G6'],
  0, 0, notes['E6'], 0,
  0, notes['A6'], 0, notes['B6'],
  0, notes['AS6'], notes['A6'], 0,
 
  notes['G6'], notes['E7'], notes['G7'],
  notes['A7'], 0, notes['F7'], notes['G7'],
  0, notes['E7'], 0, notes['C7'],
  notes['D7'], notes['B6'], 0, 0
]
tempo = [
  12, 12, 12, 12,
  12, 12, 12, 12,
  12, 12, 12, 12,
  12, 12, 12, 12,
 
  12, 12, 12, 12,
  12, 12, 12, 12,
  12, 12, 12, 12,
  12, 12, 12, 12,
 
  9, 9, 9,
  12, 12, 12, 12,
  12, 12, 12, 12,
  12, 12, 12, 12,
 
  12, 12, 12, 12,
  12, 12, 12, 12,
  12, 12, 12, 12,
  12, 12, 12, 12,
 
  9, 9, 9,
  12, 12, 12, 12,
  12, 12, 12, 12,
  12, 12, 12, 12,
]


underworld_melody = [
  notes['C4'], notes['C5'], notes['A3'], notes['A4'],
  notes['AS3'], notes['AS4'], 0,
  0,
  notes['C4'], notes['C5'], notes['A3'], notes['A4'],
  notes['AS3'], notes['AS4'], 0,
  0,
  notes['F3'], notes['F4'], notes['D3'], notes['D4'],
  notes['DS3'], notes['DS4'], 0,
  0,
  notes['F3'], notes['F4'], notes['D3'], notes['D4'],
  notes['DS3'], notes['DS4'], 0,
  0, notes['DS4'], notes['CS4'], notes['D4'],
  notes['CS4'], notes['DS4'],
  notes['DS4'], notes['GS3'],
  notes['G3'], notes['CS4'],
  notes['C4'], notes['FS4'], notes['F4'], notes['E3'], notes['AS4'], notes['A4'],
  notes['GS4'], notes['DS4'], notes['B3'],
  notes['AS3'], notes['A3'], notes['GS3'],
  0, 0, 0
]

underworld_tempo = [
  12, 12, 12, 12,
  12, 12, 6,
  3,
  12, 12, 12, 12,
  12, 12, 6,
  3,
  12, 12, 12, 12,
  12, 12, 6,
  3,
  12, 12, 12, 12,
  12, 12, 6,
  6, 18, 18, 18,
  6, 6,
  6, 6,
  6, 6,
  18, 18, 18, 18, 18, 18,
  10, 10, 10,
  10, 10, 10,
  3, 3, 3
]
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

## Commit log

2021-09-28 initial commit
    code, images and documentation for the Raspberry Pi Maker Kit v5.0
2021-11-12 add pressure measurement sensor
2024-06-24 image and documentation update
    updated PCB front view image and documentation updated to v2.0
2024-06-24 PCB Gerber files added and README update
    downloadable GERBER PCB design files made available
    [RPI_kits_PCB05-B_Cu.gbr, RPI_kits_PCB05-B_Mask.gbr, RPI_kits_PCB05-B_SilkS.gbr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]
2025-07-02 update kit to PCB in RPi maker commands etc.
2025-07-03 add motor web control files
2025-07-03 update motor drive web control
2025-07-07 kit to pCB edits
    [RPI_kits_PCB05-B_Cu.gbr, RPI_kits_PCB05-B_Mask.gbr, RPI_kits_PCB05-B_SilkS.gbr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]
2025-07-07 kits to PCB edits
    [RPI_kits_PCB05-B_Cu.gbr, RPI_kits_PCB05-B_Mask.gbr, RPI_kits_PCB05-B_SilkS.gbr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]
2026-05-19 kits to PCB updates
